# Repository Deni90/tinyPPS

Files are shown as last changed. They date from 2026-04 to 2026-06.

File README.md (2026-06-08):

## Description

TinyPPS is a pocket-sized programmable power supply built on the USB Power Delivery (PD) standard and the USB Programmable Power Supply (PPS) feature. It transforms a standard USB-C PD charger into a flexible bench-style power source by negotiating selectable output voltages and current limits directly with the charger.

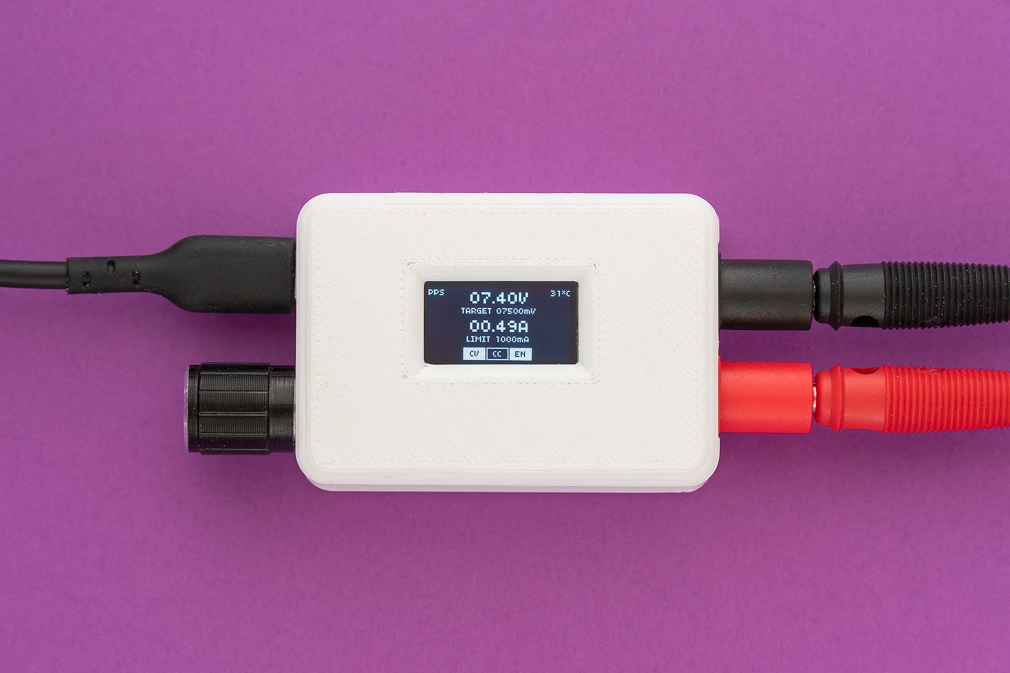
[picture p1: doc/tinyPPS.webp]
TinyPPS


## Key features

TinyPPS takes advantage of pin-compatible USB PD sink ICs (AP33772 and AP33772S), providing two feature sets within a single firmware, depending on the selected IC:

| Feature | With AP33772s | With AP33772 |
| - | - | - |
| Supported PDO profiles | fixed PDO, PPS | fixed PDO, PPS |
| Output voltage range | 3.3 - 21V | 3.3 - 21V |
| Max output current* | 5A | 5A |
| PPS voltage step size | 100mV/Step | 20mV/Step |
| Programmable current limit | 250mA/Step | 50mA/Step |
| User-switchable output | ✅ | ✅ |
| Over Voltage Protection (OVP) | ✅ → Hard Reset and Auto Restart | ✅ → Auto Restart |
| Over Current Protection (OCP) | ✅ → Output Disable | ✅ → Auto Restart |
| Under Voltage Protection (UVP) | ✅ → Output Disable | ❌ |
| Over temperature protection (OTP)** | ✅ → Output Disable | ✅ → Output Disable |
| Short-Circuit Protection (SCP) | ✅ → Output Disable | ✅ → Output Disable |

**charger and cable dependent*

***OTP is set to 85°C*

Huge thank you to **[PCBWay](https://www.pcbway.com)** for sponsoring this project!
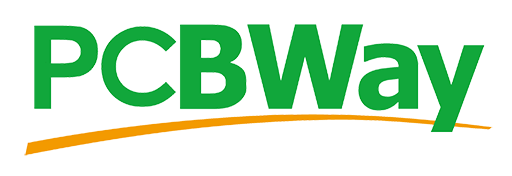
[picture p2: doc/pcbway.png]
PCBWay logo


## Firmware

The firmware is written in C++ using the Raspberry Pi Pico SDK. No external dependencies are used.

Configuring the build using CMake:

```bash
cd firmware
cmake -G Ninja -S . -B build
```

Building the firmware:

```bash
cmake --build build
```

## Flashing

There are two options to flash RP2040:
1. Via USB by pressing the `BOOT` button during power on. On a PC a new virtual drive called `RPI-RP2` should appear. Then, drag and drop a *.uf2* file onto the drive.
2. Via SWD interface by attaching a debugger like Raspberry Pi Debug Probe to the "DBG" connector and then using OpenOCD.
    ```bash
    cmake --build build --target flash
    ```

## Hardware

Schematic and PCB are designed in KiCAD 10.

Key components:

- The device is based on the **RP2040** microcontroller and **AP33772(S)** USB PD sink controller.
- A **0.96 in 128×64 SSD1306 OLED** is added to display the UI.
- A **EC11** rotary encoder is added for user input.
- **INA226** is used for measuring current and voltage. *While AP33772s provides these features, INA226 gives more precise measurements.*
- **LM73100** replaces the back-to-back NMOS switch and provides short circuit protection.
- **74LVC1G08GW,125** single 2-input AND gate is used for output enable.

## Case

3D model is made with Autodesk Fusion 360.

The case is 3D printed with ABS so it can handle higher tempeatures.

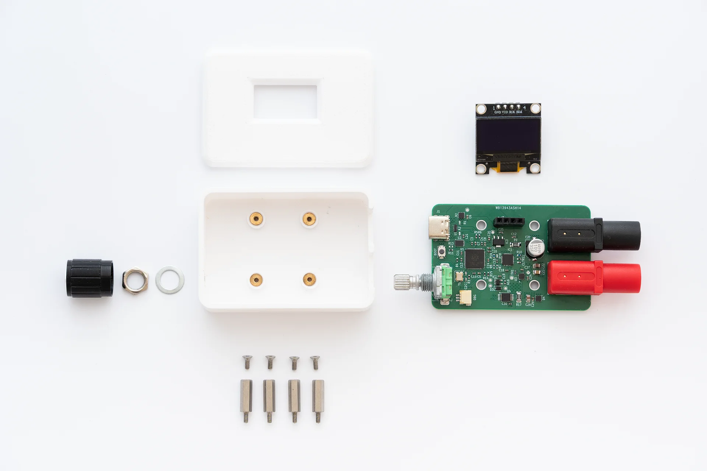
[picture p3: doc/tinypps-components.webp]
TinyPPS exploded view


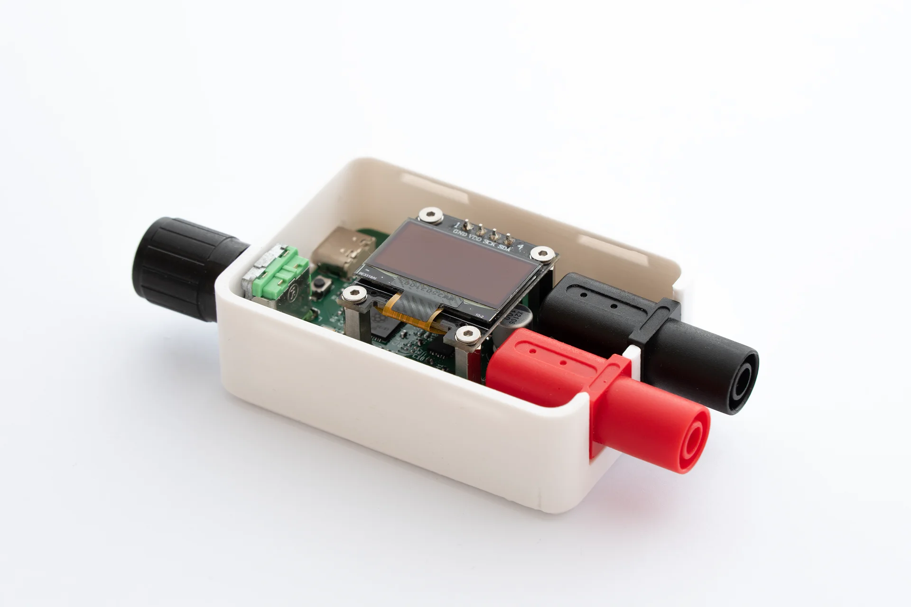
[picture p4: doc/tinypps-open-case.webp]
TinyPPS open case


## Resources

1. [Hardware design with RP2040](https://pip-assets.raspberrypi.com/categories/814-rp2040/documents/RP-008279-DS-1-hardware-design-with-rp2040.pdf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)
2. [AP33772S I2C USB PD Sink Controller EVB User Guide](https://www.diodes.com/assets/Evaluation-Boards/AP33772S-Sink-Controller-EVB-User-Guide.pdf)
3. [SSD1306](https://cdn-shop.adafruit.com/datasheets/SSD1306.pdf)
4. [INA226](https://www.ti.com/lit/ds/symlink/ina226.pdf?ts=1770072845830)

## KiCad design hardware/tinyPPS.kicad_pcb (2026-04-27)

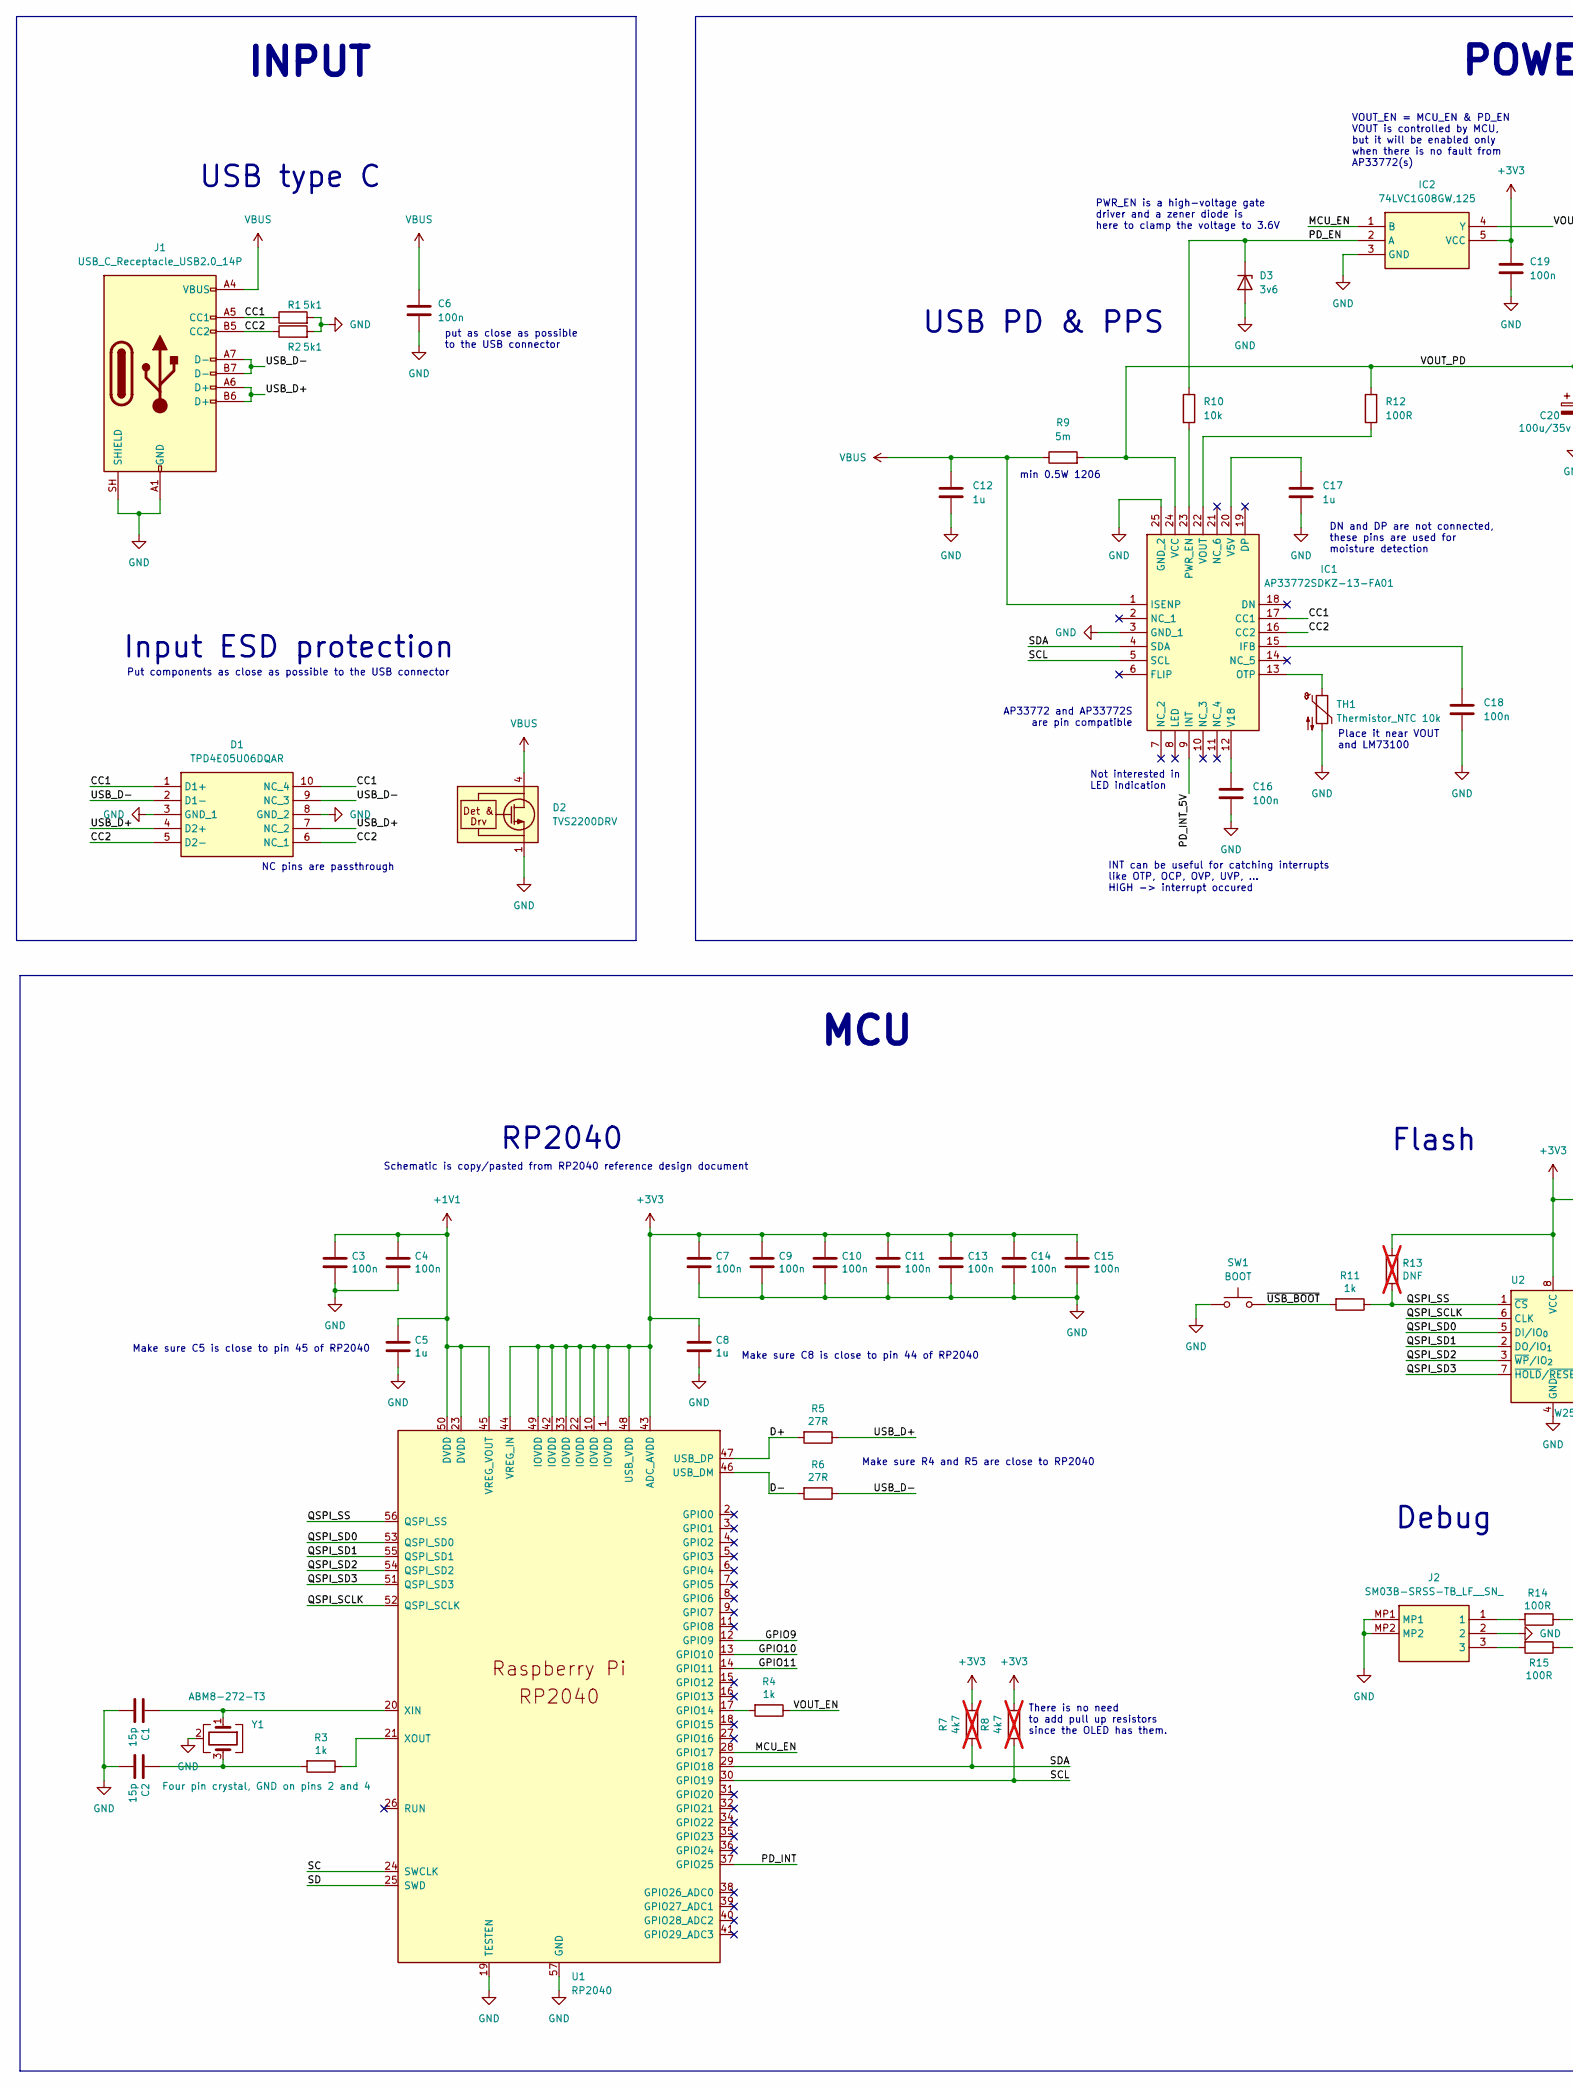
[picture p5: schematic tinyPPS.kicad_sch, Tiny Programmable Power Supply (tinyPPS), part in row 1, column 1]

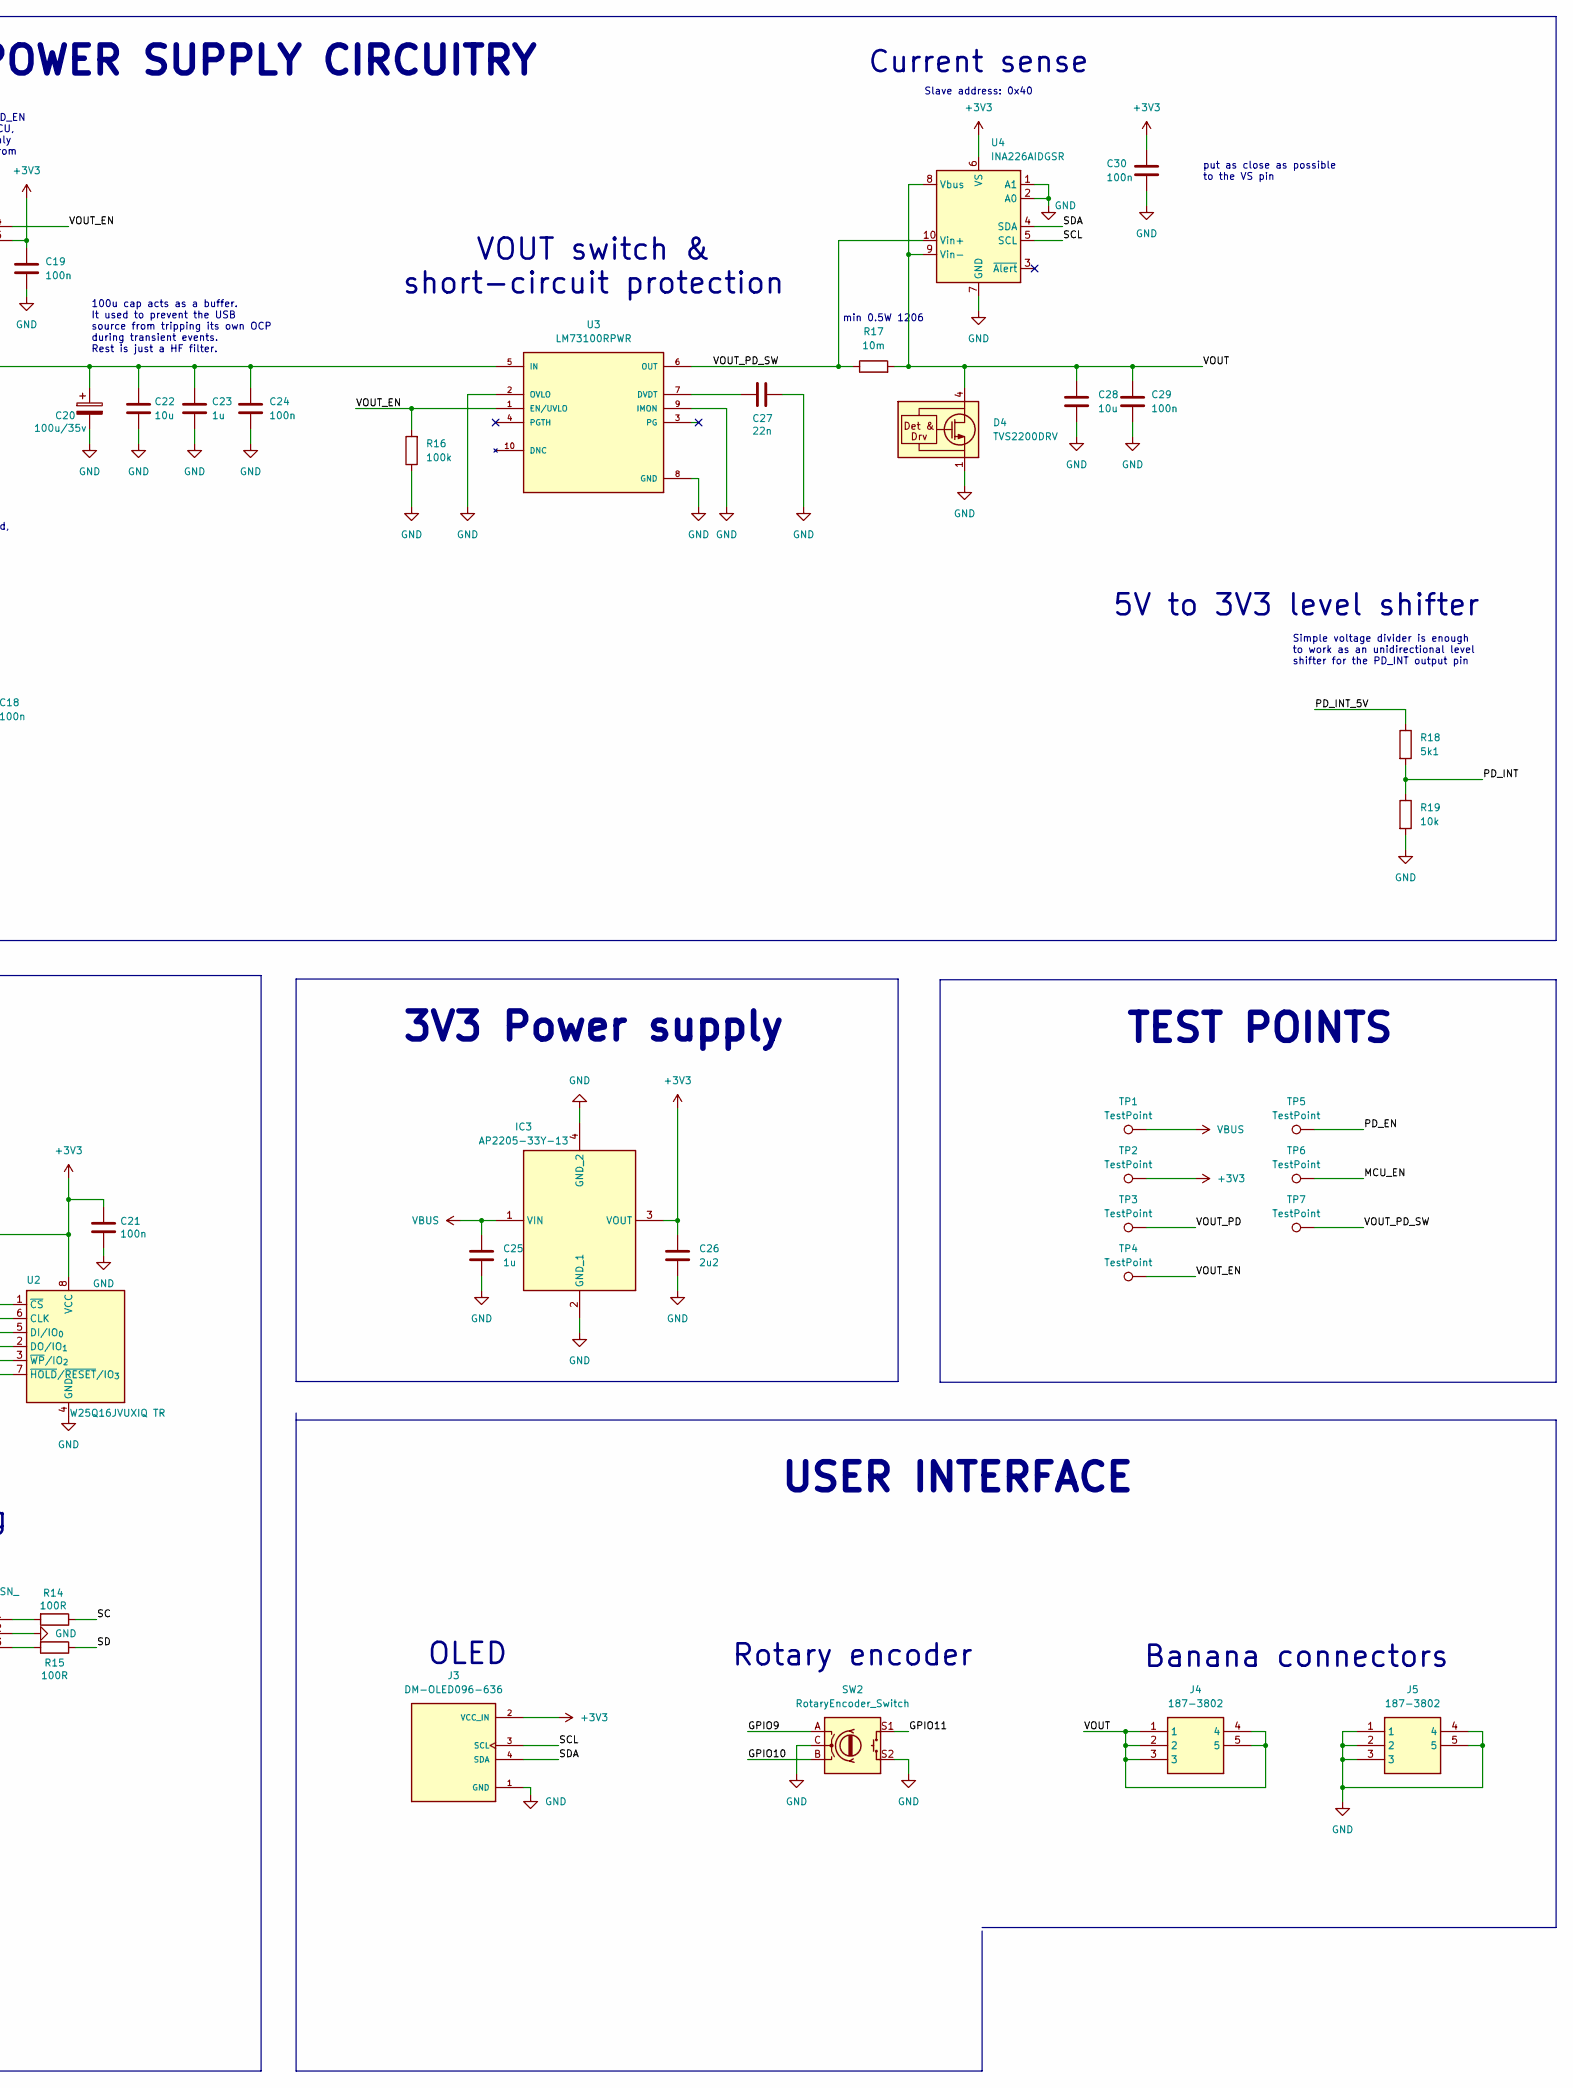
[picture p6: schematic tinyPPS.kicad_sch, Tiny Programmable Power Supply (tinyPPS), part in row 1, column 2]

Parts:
C1, C2: 15p; C_0402_1005Metric
C3, C4, C6, C7, C9, C10, C11, C13, C14, C15, C16, C18, C19, C21, C24, C29, C30: 100n; C_0402_1005Metric
C5, C8, C12, C17, C25: 1u; C_0402_1005Metric
C20: 100u/35v; CP_Elec_6.3x7.7
C22, C28: 10u; C_0805_2012Metric
C23: 1u; C_0805_2012Metric
C26: 2u2; C_0402_1005Metric
C27: 22n; C_0402_1005Metric
D1: TPD4E05U06DQAR; DQA_R-PUSON-N10_; Mouser Part Number 595-TPD4E05U06DQAR
D2, D4: TVS2200DRV; WSON-6-1EP_2x2mm_P0.65mm_EP1x1.6mm
D3: 3v6; D_SOD-323
IC1: AP33772SDKZ-13-FA01; AP33772SDKZ13FA01; Mouser Part Number 621-P33772SDKZ13FA01
IC2: 74LVC1G08GW,125; SOT65P210X110-5N; Mouser Part Number 771-74LVC1G08GW-G
IC3: AP2205-33Y-13; 2DB1132R13; Mouser Part Number 621-AP2205-33Y-13
J1: USB_C_Receptacle_USB2.0_14P; USB_C_Receptacle_GCT_USB4105-xx-A_16P_TopMnt_Horizontal
J2: SM03B-SRSS-TB_LF__SN_; SM03BSRSSTBLFSN; Mouser Part Number N/A
J3: DM-OLED096-636; MODULE_DM-OLED096-636; PARTREV 2018-09-10
J4, J5: 187-3802; 1873802; Manufacturer_Part_Number 187-3802
R1, R2, R18: 5k1; R_0402_1005Metric
R3, R4, R11: 1k; R_0402_1005Metric
R5, R6: 27R; R_0402_1005Metric
R7, R8: 4k7; R_0402_1005Metric; not fitted
R9: 5m; R_1206_3216Metric
R10, R19: 10k; R_0402_1005Metric
R12, R14, R15: 100R; R_0402_1005Metric
R13: DNF; R_0402_1005Metric; not fitted
R16: 100k; R_0402_1005Metric
R17: 10m; R_1206_3216Metric
SW1: BOOT; SW_3x4mm
SW2: RotaryEncoder_Switch; EC11 horizontal
TH1: Thermistor_NTC 10k; R_0402_1005Metric
TP1, TP2, TP3, TP4, TP5, TP6, TP7: TestPoint; TestPoint_Pad_D1.0mm
U1: RP2040; RP2040-QFN-56
U2: W25Q16JVUXIQ TR; Winbond_USON-8-1EP_3x2mm_P0.5mm_EP0.2x1.6mm
U3: LM73100RPWR; IC_LM73100RPWR; PARTREV 08/2019
U4: INA226AIDGSR; TSSOP-10_3x3mm_P0.5mm
Y1: ABM8-272-T3; Crystal_SMD_3225-4Pin_3.2x2.5mm

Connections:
+1V1: C3.1, C4.1, C5.1, U1.23 (DVDD), U1.45 (VREG_VOUT), U1.50 (DVDD)
+3V3: C7.1, C8.1, C9.1, C10.1, C11.1, C13.1, C14.1, C15.1, C19.1, C21.1, C26.1, C30.1, IC2.5 (VCC), IC3.3 (VOUT), J3.2 (VCC_IN), R7.1, R8.1, R13.1, TP2.1 (1_1), U1.1 (IOVDD), U1.10 (IOVDD), U1.22 (IOVDD), U1.33 (IOVDD), U1.42 (IOVDD), U1.43 (ADC_AVDD), U1.44 (VREG_IN), U1.48 (USB_VDD), U1.49 (IOVDD), U2.8 (VCC), U4.6 (VS)
/CC1: D1.1 (D1+), D1.10 (NC_4), IC1.17 (CC1), J1.A5 (CC1), R1.1
/CC2: D1.5 (D2-), D1.6 (NC_1), IC1.16 (CC2), J1.B5 (CC2), R2.1
/D+: R5.2, U1.47 (USB_DP)
/D-: R6.2, U1.46 (USB_DM)
/GPIO9: SW2.A, U1.12 (GPIO9)
/GPIO10: SW2.B, U1.13 (GPIO10)
/GPIO11: SW2.S1, U1.14 (GPIO11)
/MCU_EN: IC2.1 (B), TP6.1 (1_1), U1.28 (GPIO17)
/PD_EN: D3.1 (K), IC2.2 (A), R10.1, TP5.1 (1_1)
/PD_INT: R18.2, R19.1, U1.37 (GPIO25)
/PD_INT_5V: IC1.9 (INT), R18.1
/QSPI_SCLK: U1.52 (QSPI_SCLK), U2.6 (CLK)
/QSPI_SD0: U1.53 (QSPI_SD0), U2.5 (DI/IO_{0})
/QSPI_SD1: U1.55 (QSPI_SD1), U2.2 (DO/IO_{1})
/QSPI_SD2: U1.54 (QSPI_SD2), U2.3 (~WP/IO_{2})
/QSPI_SD3: U1.51 (QSPI_SD3), U2.7 (~HOLD/~RESET/IO_{3})
/QSPI_SS: R11.1, R13.2, U1.56 (QSPI_SS), U2.1 (~CS)
/SC: R14.1, U1.24 (SWCLK)
/SCL: IC1.5 (SCL), J3.3 (SCL), R8.2, U1.30 (GPIO19), U4.5 (SCL)
/SD: R15.1, U1.25 (SWD)
/SDA: IC1.4 (SDA), J3.4 (SDA), R7.2, U1.29 (GPIO18), U4.4 (SDA)
/USB_D+: D1.4 (D2+), D1.7 (NC_2), J1.A6 (D+), J1.B6 (D+), R5.1
/USB_D-: D1.2 (D1-), D1.9 (NC_3), J1.A7 (D-), J1.B7 (D-), R6.1
/VOUT: C28.1, C29.1, D4.4 (IN), D4.5 (IN), D4.6 (IN), J4.1, J4.2, J4.3, J4.4, J4.5, R17.2, U4.8 (Vbus), U4.9 (Vin-)
/VOUT_EN: IC2.4 (Y), R4.1, R16.2, TP4.1 (1_1), U3.1 (EN/UVLO)
/VOUT_PD: C20.1, C22.1, C23.1, C24.1, IC1.24 (VCC), R9.2, R12.2, TP3.1 (1_1), U3.5 (IN)
/VOUT_PD_SW: R17.1, TP7.1 (1_1), U3.6 (OUT), U4.10 (Vin+)
/~USB_BOOT: R11.2, SW1.2
GND: C1.2, C2.2, C3.2, C4.2, C5.2, C6.2, C7.2, C8.2, C9.2, C10.2, C11.2, C12.2, C13.2, C14.2, C15.2, C16.2, C17.2, C18.2, C19.2, C20.2, C21.2, C22.2, C23.2, C24.2, C25.2, C26.2, C27.2, C28.2, C29.2, C30.2, D1.3 (GND_1), D1.8 (GND_2), D2.1 (GND), D2.2 (GND), D2.3 (GND), D2.7 (GND), D3.2 (A), D4.1 (GND), D4.2 (GND), D4.3 (GND), D4.7 (GND), IC1.3 (GND_1), IC1.25 (GND_2), IC2.3 (GND), IC3.2 (GND_1), IC3.4 (GND_2), J1.A1 (GND), J1.A12 (GND), J1.B1 (GND), J1.B12 (GND), J1.SH (SHIELD), J2.2, J2.MP1, J2.MP2, J3.1 (GND), J5.1, J5.2, J5.3, J5.4, J5.5, R1.2, R2.2, R16.1, R19.2, SW1.1, SW2.C, SW2.S2, TH1.2, U1.19 (TESTEN), U1.57 (GND), U2.4 (GND), U3.2 (OVLO), U3.8 (GND), U3.9 (IMON), U4.1 (A1), U4.2 (A0), U4.7 (GND), Y1.2 (G), Y1.4 (G)
unnamed: C2.1, R3.2, Y1.3
unnamed: C18.1, IC1.15 (IFB)
unnamed: IC1.13 (OTP), TH1.1
unnamed: IC1.23 (PWR_EN), R10.2
unnamed: C17.1, IC1.20 (V5V)
unnamed: C16.1, IC1.12 (V18)
unnamed: IC1.22 (VOUT), R12.1
unnamed: J2.1, R14.2
unnamed: J2.3, R15.2
unnamed: R4.2, U1.17 (GPIO14)
unnamed: C1.1, U1.20 (XIN), Y1.1
unnamed: R3.1, U1.21 (XOUT)
unnamed: C27.1, U3.7 (DVDT)
VBUS: C6.1, C12.1, C25.1, D2.4 (IN), D2.5 (IN), D2.6 (IN), IC1.1 (ISENP), IC3.1 (VIN), J1.A4 (VBUS), J1.A9 (VBUS), J1.B4 (VBUS), J1.B9 (VBUS), R9.1, TP1.1 (1_1)

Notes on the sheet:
100u cap acts as a buffer. It used to prevent the USB source from tripping its own OCP during transient events. Rest is just a HF filter.
There is no need to add pull up resistors since the OLED has them.
AP33772 and AP33772S are pin compatible
min 0.5W 1206
MCU
Not interested in LED indication
VOUT_EN = MCU_EN & PD_EN VOUT is controlled by MCU, but it will be enabled only when there is no fault from AP33772(s)
DN and DP are not connected, these pins are used for moisture detection
INPUT
Debug
put as close as possible to the USB connector
Input ESD protection
VOUT switch & short-circuit protection
Banana connectors
OLED
Slave address: 0x40
USB PD & PPS
Place it near VOUT and LM73100
Make sure R4 and R5 are close to RP2040
Flash
3V3 Power supply
INT can be useful for catching interrupts like OTP, OCP, OVP, UVP, ... HIGH -> interrupt occured
Make sure C5 is close to pin 45 of RP2040
Schematic is copy/pasted from RP2040 reference design document
put as close as possible to the VS pin
Make sure C8 is close to pin 44 of RP2040
USER INTERFACE
NC pins are passthrough
RP2040
Current sense
Rotary encoder
POWER SUPPLY CIRCUITRY
TEST POINTS
PWR_EN is a high-voltage gate driver and a zener diode is here to clamp the voltage to 3.6V
5V to 3V3 level shifter
USB type C
Simple voltage divider is enough to work as an unidirectional level shifter for the PD_INT output pin
Put components as close as possible to the USB connector

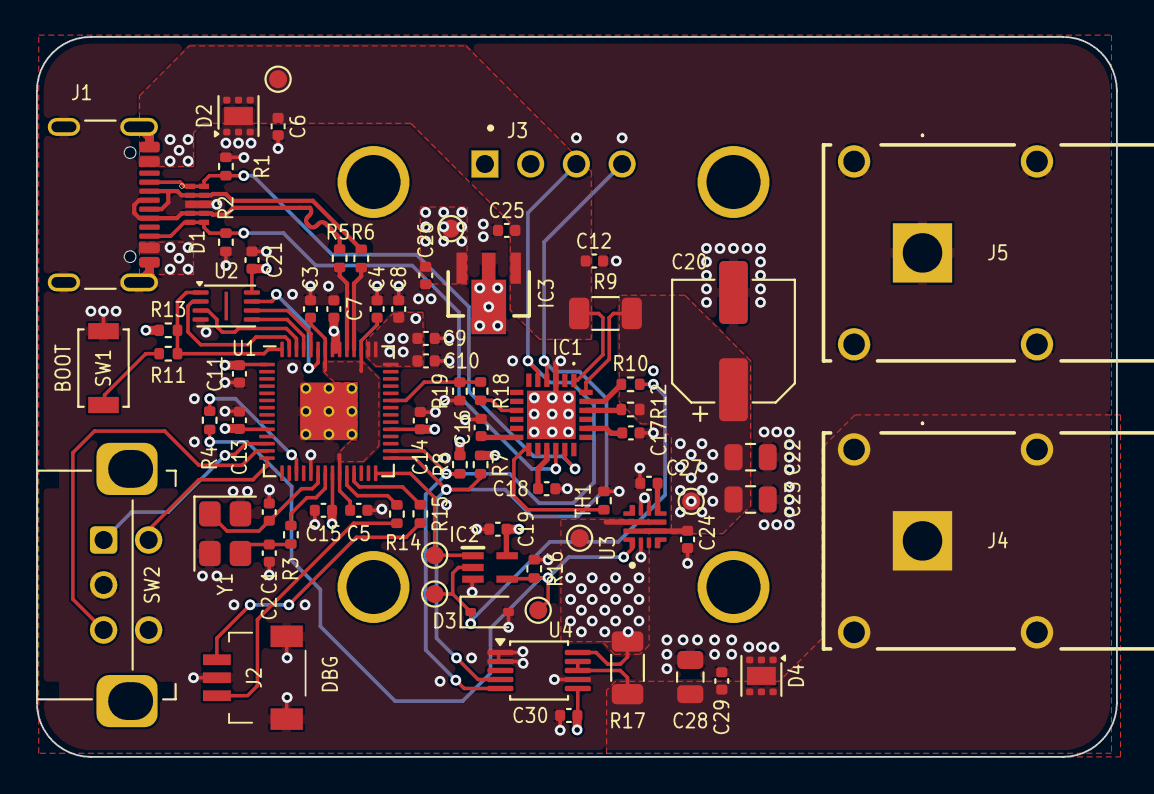
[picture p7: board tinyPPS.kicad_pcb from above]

Board: 4 copper layers, 60.0 x 40.0 mm, 76 parts (0 on the bottom side), 45 nets.

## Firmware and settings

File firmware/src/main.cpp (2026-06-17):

#include <cstdint>
#include <functional>

#include "ap33772.hpp"
#include "ap33772s.hpp"
#include "config.hpp"
#include "event.hpp"
#include "hardware_config.hpp"
#include "ina226.hpp"
#include "pdsink_iface.hpp"
#include "rotary_encoder.hpp"
#include "ssd1306.hpp"
#include "state_machine.hpp"

using hal::gpio::Direction;
using hal::gpio::Edge;
using hal::gpio::Pull;

static constexpr uint k_g_rot_enc_btn_pin = 11;
static constexpr uint k_rot_enc_a_pin = 10;
static constexpr uint k_g_rot_enc_b_pin = 9;

static constexpr i2c_inst_t* k_i2c = i2c1;
static constexpr unsigned int k_i2c_sda_pin = 18;
static constexpr unsigned int k_i2c_scl_pin = 19;
static constexpr unsigned int k_i2c_speed = 400;   // kHz

static constexpr unsigned int k_g_pd_int_pin = 25;
static constexpr unsigned int k_g_output_enable_pin = 17;
static constexpr unsigned int k_g_vout_status_pin = 14;

static constexpr uint8_t k_ina226_addr = 0x40;

// https://product.tdk.com/system/files/dam/doc/product/sensor/ntc/chip-ntc-thermistor/data_sheet/datasheet_ntcgs103jx103dt8.pdf
// based on B value:
//                  [at 25/50C] 3380K typ.
//                  [at 25/85C] 3435K+-0.7%
static constexpr unsigned int k_ntc_tr25 = 10000;
static constexpr unsigned int k_ntc_tr50 = 4164;
static constexpr unsigned int k_ntc_tr75 = 1912;
static constexpr unsigned int k_ntc_tr100 = 987;

static constexpr uint16_t k_ap33772s_vsel_min = 3300;
static constexpr uint8_t k_otp_threshold = 85;

static constexpr uint32_t k_sensor_read_period = 20;

static constexpr PicoGpioPin g_rot_enc_a_pin{k_rot_enc_a_pin};
static constexpr PicoGpioPin g_rot_enc_b_pin{k_g_rot_enc_b_pin};
static constexpr PicoGpioPin g_rot_enc_btn_pin(k_g_rot_enc_btn_pin);
static constexpr PicoGpioPin g_output_enable{k_g_output_enable_pin};
static constexpr PicoGpioPin g_vout_status{k_g_vout_status_pin};
static constexpr PicoGpioPin g_pd_int{k_g_pd_int_pin};
static constexpr PicoI2c g_i2c{k_i2c};
PicoRepeatingTimer g_timer;
RotaryEncoder g_rotary_encoder{g_rot_enc_a_pin, g_rot_enc_b_pin,
                               g_rot_enc_btn_pin};
Ssd1306_128x64 g_oled{g_i2c};
Ina226 g_ina226{g_i2c, k_ina226_addr};
Ap33772 g_ap33772{g_i2c};
Ap33772s g_ap33772s{g_i2c};
std::reference_wrapper<IPdSink> g_pdsink = g_ap33772;

volatile uint32_t g_system_time = 0;
volatile bool g_is_g_pd_interrupt_pending = false;
volatile bool g_is_g_vout_status_interrupt_pending = false;
static std::array<uint8_t, Ssd1306_128x64::getFrameBufferSize()> g_frame_buffer;

auto initialize() -> void {
    g_i2c.initialize(k_i2c_sda_pin, k_i2c_scl_pin, k_i2c_speed);
    g_rotary_encoder.initialize();
    g_output_enable.configure(Direction::Output, Pull::Down);
    g_vout_status.configure(Direction::Input, Pull::Down);
    g_vout_status.attachInterrupt(
        Edge::Falling,
        [](const GpioPin&, void*) -> void {
            g_is_g_pd_interrupt_pending = true;
        },
        nullptr);
    g_pd_int.configure(Direction::Input, Pull::Down);
    g_pd_int.attachInterrupt(
        Edge::Rising,
        [](const GpioPin&, void*) -> void {
            g_is_g_pd_interrupt_pending = true;
        },
        nullptr);
    g_pd_int.enableInterrupt(true);
    g_oled.initialize();
    g_ina226.setAveragingMode(Ina226::AveragingMode::Samples128);
    g_ina226.calibrate(5, 0.01);
    Screen::initialize(g_frame_buffer, Ssd1306_128x64::getWidth(),
                       Ssd1306_128x64::getHeight(),
                       Ssd1306_128x64::getPageHeight());
    // By default, use AP33772 if available, otherwise fall back to AP33772S
    if (g_ap33772.probe()) {
        g_ap33772.setNtc(k_ntc_tr25, k_ntc_tr50, k_ntc_tr75, k_ntc_tr100);
        g_ap33772.setOtpThreshold(k_otp_threshold);
        Ap33772::MaskReg mask;
        mask.bits.newpdo_en = 1;
        mask.bits.ocp_en = 1;
        mask.bits.otp_en = 1;
        mask.bits.ovp_en = 1;
        g_ap33772.setMask(mask);
    } else {
        g_pdsink = std::ref(g_ap33772s);
        g_ap33772s.setNtc(k_ntc_tr25, k_ntc_tr50, k_ntc_tr75, k_ntc_tr100);
        g_ap33772s.setOtpThreshold(k_otp_threshold);
        g_ap33772s.setVselMin(k_ap33772s_vsel_min);
        Ap33772s::MaskReg mask;
        mask.bits.newpdo_msk = 1;
        mask.bits.ocp_msk = 1;
        mask.bits.otp_msk = 1;
        mask.bits.ovp_msk = 1;
        mask.bits.uvp_msk = 1;
        g_ap33772s.setMask(mask);
    }
    g_timer.start(
        1, [](void*) -> void { g_system_time = g_system_time + 1; }, nullptr);
}

auto main() -> int {
    initialize();
    HardwareContext hardware{.pdsink = g_pdsink.get(),
                             .output_enable = g_output_enable,
                             .oled = g_oled};

    StateMachine state_machine{hardware};

    uint32_t last_tick_time = 0;
    uint32_t last_sensor_read_time = 0;

    while (true) {
        uint32_t current_time = g_system_time;
        uint32_t delta = current_time - last_tick_time;
        last_tick_time = current_time;

        g_rotary_encoder.handle(current_time);
        auto encoder_state = g_rotary_encoder.getState();
        if (encoder_state != RotaryEncoder::State::idle &&
            encoder_state != RotaryEncoder::State::processed) {
            state_machine.dispatch(RotaryEncoderEvent{encoder_state});
            g_rotary_encoder.clearState();
        }

        if (current_time - last_sensor_read_time >= k_sensor_read_period) {
            last_sensor_read_time = current_time;
            state_machine.dispatch(SensorUpdateEvent{g_ina226.getBusVoltage(),
                                                     g_ina226.getCurrent(),
                                                     g_pdsink.get().getTemp()});
        }

        if (g_is_g_pd_interrupt_pending) {
            g_is_g_pd_interrupt_pending = false;
            state_machine.dispatch(
                PdSinkStatusUpdateEvent{g_pdsink.get().getStatus()});
        }

        if (g_is_g_vout_status_interrupt_pending) {
            g_is_g_vout_status_interrupt_pending = false;
            state_machine.dispatch(VoutStatusUpdateEvent{g_vout_status.read()});
        }

        state_machine.dispatch(SystemTickEvent{delta});
    }
}

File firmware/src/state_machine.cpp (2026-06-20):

#include "state_machine.hpp"

#include <algorithm>
#include <cstdint>

#include "pdo_helper.hpp"

static constexpr uint8_t k_retry_count = 20;
static constexpr uint32_t k_timeout_period = 200;             // ms
static constexpr uint32_t k_state_transition_period = 1500;   // ms
static constexpr uint32_t k_big_step_period = 100;            // ms
static constexpr uint32_t k_blinking_period = 500;            // ms
static constexpr uint32_t k_double_click_period = 1000;       // ms
static constexpr uint32_t k_ui_refresh_period = 20;           // ms
static constexpr uint32_t k_fault_recovery_period = 1000;     // ms
static constexpr uint32_t k_sensor_update_period = 200;       // ms
static constexpr uint32_t k_ramp_up_period = 500;             // ms

static constexpr uint16_t k_big_step_size = 250;
static constexpr float k_low_voltage_threshold = 0.5F;
static constexpr uint8_t k_low_voltage_reading_count = 10;

static constexpr std::string_view k_menu_title = "Available PDOs";

inline auto operator++(MainScreenSelection& selection) -> MainScreenSelection& {
    using T = std::underlying_type_t<MainScreenSelection>;
    selection = static_cast<MainScreenSelection>(
        (static_cast<T>(selection) + 1) %
        static_cast<T>(MainScreenSelection::Count));
    return selection;
}

inline auto operator--(MainScreenSelection& selection) -> MainScreenSelection& {
    int prev = (static_cast<int>(selection) - 1 +
                static_cast<int>(MainScreenSelection::Count)) %
               static_cast<int>(MainScreenSelection::Count);
    selection = static_cast<MainScreenSelection>(prev);
    return selection;
}

static auto adjustAndClamp(uint16_t& value, uint16_t step, uint16_t min_val,
                           uint16_t max_val, int8_t multiplier) -> void {
    // 32-bit signed int is wide enough to prevent uint16_t underflow/overflow
    int32_t current = value;
    int32_t total_change = static_cast<int32_t>(step) * multiplier;
    int32_t result = current + total_change;
    // Clamp and cast back to uint16_t
    value = static_cast<uint16_t>(std::clamp(
        result, static_cast<int32_t>(min_val), static_cast<int32_t>(max_val)));
}

StateMachine::StateMachine(HardwareContext& hardware) : m_hw(hardware) {
    renderUI();
}

auto StateMachine::handleEvent(InitState& state, const SystemTickEvent& event)
    -> void {
    if (state.retry_count < k_retry_count) {
        state.elapsed_time += event.delta;
        if (state.elapsed_time >= k_timeout_period) {
            state.elapsed_time = 0;
            state.retry_count++;
            state.screen.updateProgress();
        }
    } else {
        // Reached max retries, load a default config and transition to main
        // state
        state.screen.setPdoProfileCount(0);
        state.transition_time += event.delta;
        if (state.transition_time >= k_state_transition_period) {
            insertConfig(ConfigBuilder::buildDefault());
            m_current_state = MainStateBuilder::buildFromConfig(m_configs[0]);
            ;
        }
    }
    renderUI();
}

auto StateMachine::handleEvent(InitState&, const PdSinkStatusUpdateEvent& event)
    -> void {
    if (event.status.caps_received) {
        m_current_state = LoadingState{};
    }
}

auto StateMachine::handleEvent(LoadingState& state,
                               const SystemTickEvent& event) -> void {
    if (!state.are_pdos_loaded) {
        state.are_pdos_loaded = true;
        state.pdo_count = m_hw.pdsink.getPDSourcePowerCapabilities();
        for (auto i = 0; i < state.pdo_count; ++i) {
            IPdSink::Pdo pdo;
            if (m_hw.pdsink.getPdo(i, pdo) &&
                pdo.type != IPdSink::PdoType::AVS) {
                // Skip AVS PDOs, since the HW is not capable of handling them
                insertConfig(ConfigBuilder::buildWithPdo(pdo));
            }
        }
        state.screen.setPdoProfileCount(state.pdo_count);
    } else {
        state.transition_time += event.delta;
        if (state.transition_time >= k_state_transition_period) {
            if (state.pdo_count == 1) {
                auto next_state =
                    MainStateBuilder::buildFromConfig(m_configs[0]);
                m_hw.pdsink.setPdoOutput(next_state.config.pdo.index,
                                         next_state.user_voltage,
                                         next_state.user_current);
                m_current_state = next_state;
            } else {
                m_current_state =
                    MenuStateBuilder::build(getActiveConfigs(), 0);
            }
        }
    }
    renderUI();
}

auto StateMachine::handleEvent(MenuState& state,
                               const RotaryEncoderEvent& event) -> void {
    // Handle encoder states
    if (event.encoder_state == RotaryEncoder::State::btn_short_press) {
        auto next_state = MainStateBuilder::MainStateBuilder::buildFromConfig(
            m_configs[state.screen.getSelectedMenuItem()]);
        m_hw.pdsink.setPdoOutput(next_state.config.pdo.index,
                                 next_state.user_voltage,
                                 next_state.user_current);
        m_current_state = next_state;
    }
    // Update selected menu item based on encoder direction
    if (event.encoder_state == RotaryEncoder::State::rot_inc) {
        state.screen.selectNextMenuItem();
    } else if (event.encoder_state == RotaryEncoder::State::rot_dec) {
        state.screen.selectPreviousMenuItem();
    }
    renderUI();
}

auto StateMachine::handleEvent(MainState& state, const SystemTickEvent& event)
    -> void {
    state.updateStateTimers(event);
    // Handle blinking state for value editing mode
    if (state.is_editing && state.blinking_time >= k_blinking_period) {
        state.blinking_time = 0;
        state.blinking_state = !state.blinking_state;
    }
    // Determine visibility based on whether we are editing or static
    bool active_state = state.is_editing ? state.blinking_state : true;
    // Map selection to the final screen states
    bool highlight_voltage = (state.selection == Voltage) && active_state;
    bool highlight_current = (state.selection == Current) && active_state;
    // Update screen state based on selection and editing state
    state.screen.selectTargetVoltage(highlight_voltage)
        .selectTargetCurrent(highlight_current);
    state.handleFaultRecovery(m_hw);
    // Update screen with sensor data periodically
    if (state.sensor_update_time >= k_sensor_update_period) {
        state.sensor_update_time = 0;
        state.screen.setMeasuredVoltage(state.measured_voltage);
        state.screen.setMeasuredCurrent(state.measured_current);
        state.screen.setTemperature(state.measured_temperature);
    }
    state.handleShortCircuitDetection(m_hw);
    // Update UI periodically
    if (state.ui_refresh_time >= k_ui_refresh_period) {
        state.ui_refresh_time = 0;
        renderUI();
    }
}
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

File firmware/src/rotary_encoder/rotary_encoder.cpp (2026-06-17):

#include "rotary_encoder.hpp"

#include <array>
#include <cstdint>

using hal::gpio::Direction;
using hal::gpio::Pull;

static constexpr uint32_t k_debounce_time = 50;       // ms
static constexpr uint32_t k_long_press_time = 1000;   // ms

RotaryEncoder::RotaryEncoder(const GpioPin& a_gpio, const GpioPin& b_gpio,
                             const GpioPin& btn_gpio)
    : m_state(RotaryEncoder::State::idle), m_a_gpio(a_gpio), m_b_gpio(b_gpio),
      m_btn_gpio(btn_gpio) {}

auto RotaryEncoder::initialize() -> void {
    m_a_gpio.configure(Direction::Input, Pull::Up);
    m_b_gpio.configure(Direction::Input, Pull::Up);
    m_btn_gpio.configure(Direction::Input, Pull::Up);
}

auto RotaryEncoder::handle(uint32_t now_ms) -> void {
    // reset rotary_encoder state to idle if processed
    if (m_state == RotaryEncoder::State::processed) {
        // if the rotary_encoder is still pressed do nothing
        if (!m_btn_gpio.read()) {
            return;
        }
        // rotary_encoder is released (high), reset flags
        m_state = RotaryEncoder::State::idle;
        m_is_debounce_started = false;
        m_is_button_pressed = false;
        m_is_button_handling_started = false;
    }

    // Handle button press
    bool current_btn_state = m_btn_gpio.read();
    if (current_btn_state != m_last_btn_state) {
        m_last_btn_state = current_btn_state;
        m_debounce_time_ms = now_ms;
    } else if ((now_ms - m_debounce_time_ms) >= k_debounce_time) {
        m_is_button_pressed = !current_btn_state;
    }

    // Encoder routine. Updates counter if they are valid
    // and if rotated a full indent
    static uint8_t old_AB = 3;   // Lookup table index
    static int8_t encval = 0;    // Encoder value
    constexpr std::array<int8_t, 16> k_enc_states = {
        0, -1, 1, 0, 1, 0, 0, -1, -1, 0, 0, 1, 0, 1, -1, 0};   // Lookup table

    old_AB <<= 2;   // Remember previous state
    if (!m_a_gpio.read()) {
        old_AB |= 0x02;   // Add current state of pin A
    }
    if (!m_b_gpio.read()) {
        old_AB |= 0x01;   // Add current state of pin B
    }
    encval += k_enc_states[(old_AB & 0x0f)];
    // Update counter if encoder has rotated a full indent, that is at least 4
    // steps
    if (encval > 3) {   // Four steps forward
        encval = 0;
        if (m_is_button_pressed) {
            m_state = RotaryEncoder::State::rot_inc_while_btn_press;
            return;
        }
        m_state = RotaryEncoder::State::rot_inc;
        return;
    }
    if (encval < -3) {   // Four steps backwards
        encval = 0;
        if (m_is_button_pressed) {
            m_state = RotaryEncoder::State::rot_dec_while_btn_press;
            return;
        }
        m_state = RotaryEncoder::State::rot_dec;
        return;
    }

    // decide betweeen short and long press
    // start timer for long press
    if (m_is_button_pressed && !m_is_button_handling_started) {
        m_is_button_handling_started = true;
        m_long_press_time_ms = now_ms;
    }
    if (m_is_button_handling_started) {
        // if rotary_encoder is still pressed after
        if (!m_btn_gpio.read()) {
            if ((now_ms - m_long_press_time_ms) >= k_long_press_time) {
                m_state = RotaryEncoder::State::btn_long_press;
            }
        } else {
            m_state = RotaryEncoder::State::btn_short_press;
        }
    }
}

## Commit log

2025-05-25 Implement a basic TinyPPS GUI layout and control
    - Implement OLED display driver
    - Implement rotary encoder driver
    - Implement main menu and main screens
    - Handle rotary encoder states
2025-06-03 Add schematic & PCB
    [tinyPPS.kicad_pcb, tinyPPS.kicad_sch]
2025-08-05 Measure current and voltage with INA226
    - Implement a basic INA226 module API
    - Measure voltage and current in main state
2025-08-11 Remove LED connection and update PD_INT level shifter
    [tinyPPS.kicad_pcb, tinyPPS.kicad_sch]
2025-08-12 Use back-to-back N MOS switch with common source
    [tinyPPS.kicad_pcb, tinyPPS.kicad_sch]
2025-08-12 Update silkscreen width and thickness
    [tinyPPS.kicad_pcb]
2025-08-12 Replace led indicator with mode
2025-08-17 Minor changes on the PCB
    [tinyPPS.kicad_pcb]
2025-08-18 Change rotary encoder to a horizontal type
    - Re-route the PCB
    - Make PCB with smaller (60mm)
    [tinyPPS.kicad_pcb, tinyPPS.kicad_sch]
2025-08-23 Update PCB routing - use +3v3 and GND planes
    [tinyPPS.kicad_pcb, tinyPPS.kicad_sch]
2025-08-29 Change PCB size to 60x40mm and update INA226 circuit
    [tinyPPS.kicad_pcb, tinyPPS.kicad_sch]
2025-12-03 Change footprint for flash to WSON-8 6x5mm and re-route the PCB
    [tinyPPS.kicad_pcb, tinyPPS.kicad_sch]
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2026-01-24 Fix reading current from INA226
    - Remove output filterfing from INA266, cause it may not be correctly
    implemented.
    [tinyPPS.kicad_pcb, tinyPPS.kicad_sch]
2026-01-24 Refactor INA226 API
    - Change calibration function. Make it based on
    https://github.com/RobTillaart/INA226 Arduino API
    - Add functions for getting/setting config parameters
    - Update read current and voltage to return float values.
2026-01-25 Read and show the number of PDOs from AP33772s
    - Add an app33772s module used for the driver code
    - Define register objects (Status, Mask, System, SrcPdo and PdReqMsg)
    - Implement a basic API for getting status, setting NTC values, control the
    ouput enable NMOS switch and read PDOs from a USB power source.
2026-01-26 Refactor config module
    - Create PdoType enum representing PDO types (FIX, AVS, PPS, NONE)
    - Rename profile to pdo_profile
    - Rename mode to supply_mode
    - Update ConfigBuilder with buildDefault
    [tiny_pps.cpp]
2026-01-28 Implement PDO selection
    - Extend Ap33772s with setVselMin function to enable voltages bellow 5V.
    - Extend Ap33772s with getPdo funtion for retrieving PDO at specified index.
    - Extend Ap33772s with setPdoOutput function for selecting PDO with output
    voltage and current.
    - Update config to use Pdo structure.
    - Integrate PDO selection into main module.
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2026-01-29 Fix showing default target V for a when there is no PDO available
    The issue is fixed by setting voltage_min to 5000 in Pdo's constructor.
    [ap33772s.cpp]
2026-01-29 Screen: Extend printChar* and printString* functions with dry_run flag
    If dry_run is true, no text will be rendered; Functions will only compute the
    required width.
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2026-02-02 Ssd1306: Optimize display() to use page-level dirty tracking
    - Partially update the display with page-level dirty tracking to reduce the
    time spent on i2c transfers.
    - This change solves the issue with blocked loop resulting in missed rotary
    encoder events.
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2026-02-02 Handle faults triggered by the PD_INT interrupt
    - Attach an interrupt to PD_INT pin
    - Disable output if fault is raised
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2026-03-26 Schematic: Remove i2c level shifters
    AP33772s' i2c can operate at 3V3, there is no need for level shifters.
    [tinyPPS.kicad_pcb, tinyPPS.kicad_sch]
2026-03-26 Update README fix values for output voltage range
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2026-04-27 TinyPPS: Remove i2c handling from ISR
    ISR now only sets an interrupt flag. I2C read is handled in main state.
2026-04-27 HAL: Extend HAL with IPdSink for USB PD Sink control
    IPdSink class provides a generic API for USB Power Delivery Sink hardware. This
    addition opens the possibility to support different types of PD controllers
    without modifying code in the main module.
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2026-04-27 PCB: Unroute PCB
    [tinyPPS.kicad_pcb]
2026-04-27 Hardware: Switch to 4-layer board setup
    Schematic:
    - Add TVS diodes to input and output
    - Support both AP33772 and AP33772s
    - Replace back-to-back NMOS swith with a single LM73100. AP33772(s) has a
    PWR_EN pin that is used as a gate driver for the NMOS switch. Voltage levels
    of the PWR_EN can be greater than the maximum rating of 6.5V for LM73100.
    Because of this, a Zener diode has been added to act as a voltage clamp.
    - Since AP33772 has no capability to enable/disable the output (LM73100) via
    firmware (it is automatically enabled on successfull PD negotiation), a
    single 2-input AND gate (74LVC1G08GW,125) is added where one input is the
    PWR_EN signal from AP33772(s) and the other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
    [tinyPPS.kicad_pcb, tinyPPS.kicad_sch]
2026-04-27 TinyPPS: Add support for AP33772
    - Implement an AP33772 module based on IPdSink
    - Integrate AP33772 to TinyPPS
    - Extend probe function to detect AP33772 by default and fallback to AP33772s
    if it is not detected
2026-05-05 TinyPPS: Move enableOutput from IPdSink to TinyPPS
    - Leave VOUTCTL as auto for AP33772S
    - Control vout via GPIO pin connected to AND gate
2026-05-24 PicoHal:: Fix clang-tidy warnings
    - Modernize C++ code
    - Use better variable/argument names
    [pico_gpio.cpp, pico_i2c.cpp]
2026-05-24 Ina226: Fix clang-tidy warnings
    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
    [ina226.cpp]
2026-05-24 RotaryEncoder: Fix clang-tidy warnings
    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
    [rotary_encoder.cpp]
2026-05-25 Ap33772(s): Fix clang-tidy warnings
    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
    [ap33772.cpp, ap33772s.cpp]
2026-05-25 RotaryEncoder: Refactor Handle() function
    - Move static variables from Handle() to class members to enable proper
    handling across multiple objects
    - Simplify button debounce logic
2026-05-25 Ap33772s: Fix build error(s)
    [ap33772s.cpp]
2026-05-26 TinyPPS: Refactor Menu state handling
    - Introduce MenuStateData struct for storing state data
    - Remove unnecessary while loop from the state handler function
    - Use switch/case instead of if/else to improve readability
2026-05-26 TinyPPS: Refactor Main state handling
    - Introduce MainStateData struct for storing state data
    - Move creation of default config in case of no profiles detected to init state
    handler
    - Use m_system_time for calculating time based operations
    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
2026-05-27 TinyPPS: Refactor menu and main state handlers
    - Move MenuScreen to be part of MenuStateData
    - Handle clearing encoder state at one place instead of clearing in every
    encoder state inside switch/case
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2026-05-27 TinyPPS: Use std::reference_wrapper for m_pd_sink
    - During initialization check is AP33772 connected to i2c bus. If not, fallback
    to AP33772s.
2026-05-29 CMakeLists.txt: Update config to work with the v2 PCB
    - Set PICO_BOARD to "none"
    - Disable exceptions and RTTI (not related to v2 PCB)
2026-05-29 PicoI2c: Update the module to work with any i2c_inst_t
    - Update i2c pins and i2c_inst_t to match new PCB layout
2026-05-30 TinyPPS: Make a fixed 250mA/mV big step
    - Remove magic numbers for calculating big steps for voltage and current when
    incrementing/decrementing values
    [tiny_pps.cpp]
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2026-05-30 TinyPPS: Refactor handleMainState
    - Combine handling rot_inc and rot_dec states of rotary encoder
    - Fix switching back to menu state -> prevent going back if there is only one
    PDO available
    [tiny_pps.cpp]
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2026-05-30 Screen: Used fixed size statically allocated frame buffer
    - Fix screen size to 128x64px.
    - Remove dynamic allocation of the frame buffer and make it shared across all
    sceens.
    - Update build() function to return a reference to FrameBuffer.
    - Update all screens to use the new buffer.
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2026-06-01 Ina226: Revert back to 2379d03 and improve it
    [ina226.cpp, main.cpp]
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2026-06-02 StateMachine: Handle when the LM73100 turns off the output due to a short circuit
    - Introduce a ramp-up period when enabling the output.
    - Turn off the output only if the low voltage is detected for the configured
    ammount of times.
    [state_machine.cpp]
2026-06-04 Hardware: Add a comment about how to choose the correct shunt
    - AP33772 and AP33772S are using different shunts
    [tinyPPS.kicad_sch]
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2026-06-14 Ssd1306: Refactor module to use modern C++ features
    - Use trailing return type
    - Update display() to use span for frame buffer
    - Replace run-time screen type handling with a template parameter for height
    - Use std::array for m_old_fb
    - Replace memcmp and memcpy with functions from std::ranges
    [main.cpp, state_machine.cpp]
2026-06-14 Screen: Remove hardcoded screen dimensions
    - Instead of using hardcoded screen dimension, they are now get from the oled
    screen. Screen no longer has a static std::array, instead a std::span. The
    frame buffer is now created in main module and then the Screen is initialized
    via static initializer.
    [main.cpp]
2026-06-15 IGpio, PicoGpio: Improve const-correctness
    Mark methods as const since they do not modify internal class state.
    [main.cpp, pico_gpio.cpp]
2026-06-17 HAL: Refactor GPIO to use static polymorphism
    - Replace IGpio virtual interface with a compile-time GpioPin concept
    - Move Direction, Pull, Edge enums and IrqCallback under the hal::gpio
    namespace
    - Create hardware_config.hpp to handle aliases for concrete hardware classes
    - Update modules to consume the new GpioPin type alias
    - Mark driver constructors constexpr to force pin data into the .rodata section
    [main.cpp, pico_gpio.cpp, rotary_encoder.cpp]
2026-06-17 HAL: Refactor I2C to use static polymorphism
    - Replace II2c virtual interface with a compile-time I2c concept
    - Update all modules to consume the new I2c type alias
    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
    [ap33772.cpp, ap33772s.cpp, ina226.cpp]
2026-06-17 HAL: Refactor RepeatingTimer to use static polymorphism
    - Replace IRepeatingTimer virtual interface with a compile-time
    RepeatingTimer concept
    - Move Callback under the hal::timer namespace
    [main.cpp]
2026-06-17 CMakeLists.txt: Add -Wall to CMAKE_CXX_FLAGS and fix warnings
    [ap33772.cpp, ap33772s.cpp, ina226.cpp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]
2026-06-17 CMakeLists.txt: Add -Wpedantic to CMAKE_CXX_FLAGS and fix warnings
    Fix warnings related to anonymous structs
    [ap33772.cpp, ap33772s.cpp, main.cpp]
2026-06-17 CMakeLists.txt: Add -Wextra to CMAKE_CXX_FLAGS and fix warnings
    [main.cpp, state_machine.cpp]
